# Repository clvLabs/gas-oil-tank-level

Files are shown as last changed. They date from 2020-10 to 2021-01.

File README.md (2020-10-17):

# gas-oil-tank-level

Easy gas oil tank level meter using an Arduino and a *ping* sensor

## Hardware

* Arduino Nano
* Ping sensor
* OLED screen
  * 2 3K3 resistors (I2C pullups)
* 2 buttons
  * 2 10K resistors (pullups)

## Software

### Requirements

This project has been developed with PlatformIO, you can compile it with the stock Arduino IDE, but you'll have a nicer time with PlatformIO...

### Configuration

Keeping both buttons pressed for `BUTTON_HOLD_TIME` will enter configuration mode, in which you can set `MIN_LEVEL_CM` and `MAX_LEVEL_CM`. These settings will be stored on EEPROM.

To change other settings you have to edit `src/config.h`.

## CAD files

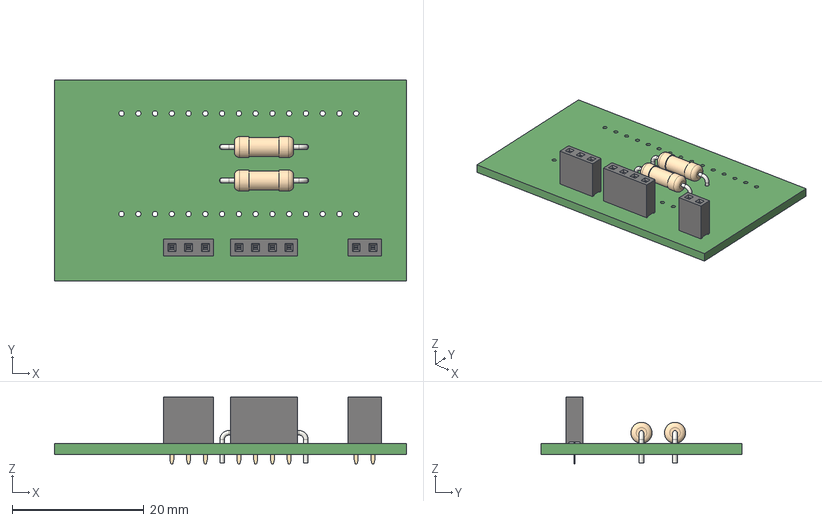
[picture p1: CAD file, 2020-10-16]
resources/schematics/main-board-multi/main-board/3d/main-board.step
53.3 x 30.5 x 10.1 mm

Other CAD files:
resources/schematics/main-board-multi/main-board/3d/main-board.stl

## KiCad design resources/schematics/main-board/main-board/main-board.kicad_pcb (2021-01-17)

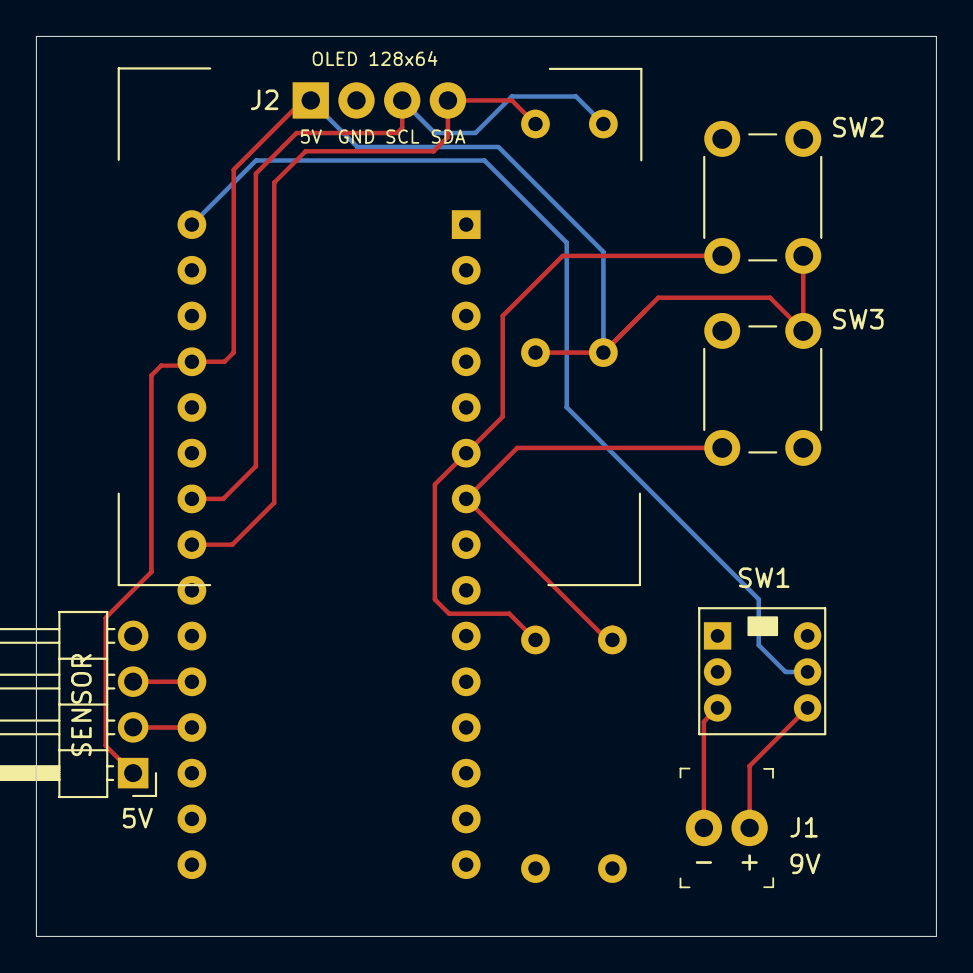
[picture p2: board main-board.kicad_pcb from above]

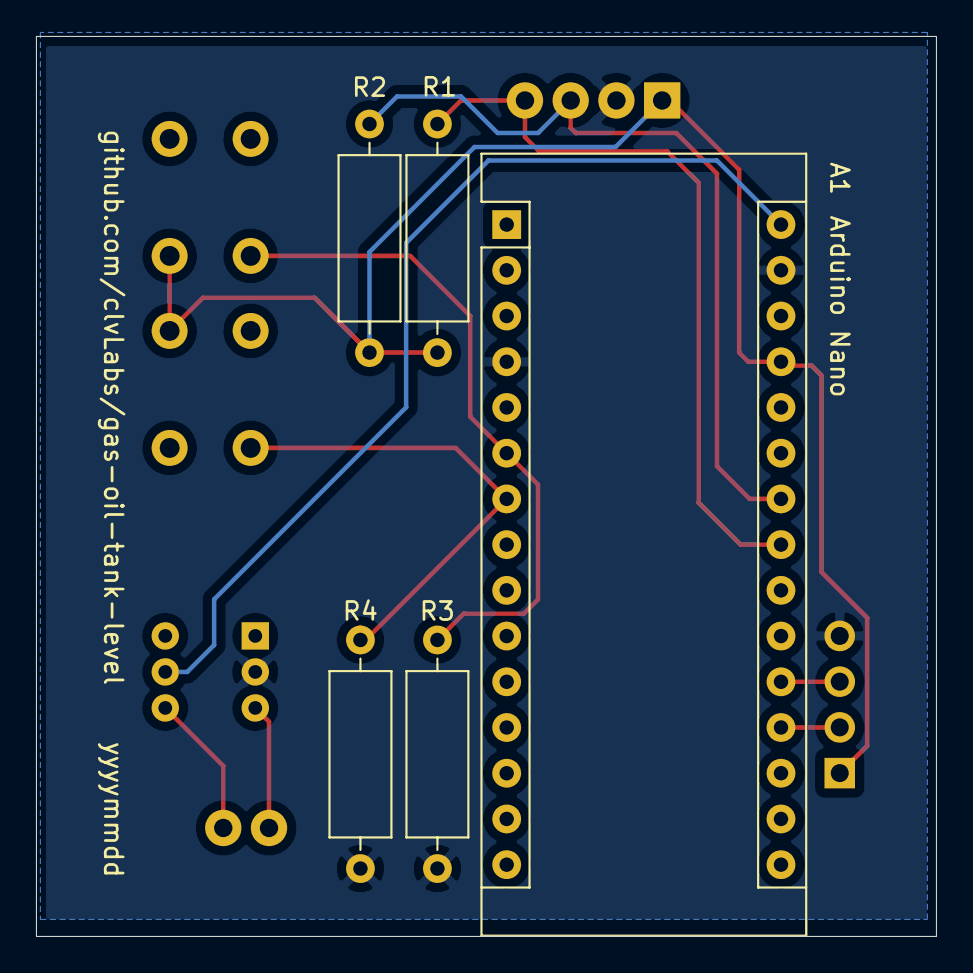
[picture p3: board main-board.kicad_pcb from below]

Board: 2 copper layers, 50.0 x 50.0 mm, 11 parts (5 on the bottom side), 11 nets.

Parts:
A1: Arduino_Nano_v3.x; Arduino_Nano
J1: Conn_01x02_Female; PinHeader_1x2_P2.54mm_Drill1.02mm
J2: Conn_01x04_Female; OLED_128X64
J3: Conn_01x04_Female; PinHeader_1x04_P2.54mm_Horizontal
R1, R2: 3.3K; R_Axial_DIN0309_L9.0mm_D3.2mm_P12.70mm_Horizontal
R3, R4: 10K; R_Axial_DIN0309_L9.0mm_D3.2mm_P12.70mm_Horizontal
SW1: SW_Push_DPDT; Switch_DPDT_7x7mm
SW2, SW3: SW_Push_45deg; SW_PUSH_6mm_H7.3mm

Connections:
+5V: A1.27, J2.1, J3.1, R1.1, R2.1, SW2.2, SW3.2
BATT_GND: J1.1, SW1.3
BATT_VIN: J1.2, SW1.6
BUTTON_DOWN_PIN: A1.7, R4.2, SW3.1
BUTTON_UP_PIN: A1.6, R3.2, SW2.1
GND: A1.4, A1.29, J2.2, J3.4, R3.1, R4.1, SW1.2
I2C_SCL: A1.24, J2.3, R2.2
I2C_SDA: A1.23, J2.4, R1.2
PING_ECHO_PIN: A1.20, J3.3
PING_TRIGGER_PIN: A1.19, J3.2
VIN: A1.30, SW1.5

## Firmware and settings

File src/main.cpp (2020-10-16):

#include "Arduino.h"
#include "3rdParty/JC_Button/JC_Button.h"
#include "config.h"
#include "utils/eepromcfg.h"
#include "ui/uimgr.h"

// Globals
DISPLAY_CLASS u8g(U8G_I2C_OPT_NONE | U8G_I2C_OPT_DEV_0); // I2C / TWI
Button btnUp(BUTTON_UP_PIN, BUTTON_DEBOUNCE_MS, BUTTON_INTERNAL_PULLUP, BUTTON_INVERT);
Button btnDown(BUTTON_DOWN_PIN, BUTTON_DEBOUNCE_MS, BUTTON_INTERNAL_PULLUP, BUTTON_INVERT);
ui::UIMgr uiMgr;
EEPROMCfg cfg;

void setup()
{
#ifdef SERIAL_OUTPUT_ENABLED
    Serial.begin(9600);
    Serial.println("Jelou!");
#endif

    pinMode(PING_TRIGGER_PIN, OUTPUT);
    pinMode(PING_ECHO_PIN, INPUT);

    pinMode(BUTTON_UP_PIN, INPUT);
    pinMode(BUTTON_DOWN_PIN, INPUT);

    u8g.setColorIndex(1);
    btnUp.begin();
    btnDown.begin();

    uiMgr.setup(&cfg, &u8g, &btnUp, &btnDown);
}

void loop()
{
    uiMgr.loop();
    delay(LOOP_SLEEP_MS);
}

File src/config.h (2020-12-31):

#pragma once

#include "Arduino.h"
#include "U8glib.h"

// Program EEPROM signature
static const int PROGRAM_EEPROM_SIGNATURE = 3014;

// Serial output (comment to disable)
// #define SERIAL_OUTPUT_ENABLED

// Distance sensor
static const uint8_t PING_TRIGGER_PIN = A0;
static const uint8_t PING_ECHO_PIN = A1;
static const unsigned int PING_MAX_DISTANCE = 500; // See NewPing.h

// Main loop sleep
static const int LOOP_SLEEP_MS = 10;

// Buttons
static const uint8_t BUTTON_DEBOUNCE_MS = 25;
static const bool BUTTON_INTERNAL_PULLUP = false;
static const bool BUTTON_INVERT = false;
static const int BUTTON_HOLD_TIME = 2000;
static const int BUTTON_RAMP1_TIME = 500;
static const int BUTTON_RAMP2_TIME = 4000;

static const uint8_t BUTTON_UP_PIN = 3;
static const uint8_t BUTTON_DOWN_PIN = 4;

// Display
#define DISPLAY_CLASS U8GLIB_SSD1306_128X64
static const int DISPLAY_WIDTH = 128;
static const int DISPLAY_HEIGHT = 64;
static const int DISPLAY_MINX = 0;
static const int DISPLAY_MINY = 0;
static const int DISPLAY_MAXX = DISPLAY_MINX + DISPLAY_WIDTH - 1;
static const int DISPLAY_MAXY = DISPLAY_MINY + DISPLAY_HEIGHT - 1;

// Level calibration
static const unsigned int MIN_LEVEL_CM_DEFAULT = 100;
static const unsigned int MAX_LEVEL_CM_DEFAULT = 19;

// Low battery alarm
static const long LOWBATT_PANIC_MODE_THRESHOLD_MV = 2000; // 2.000V

// Blink timing
static const unsigned int BLINK_ON_TIME = 500;
static const unsigned int BLINK_OFF_TIME = 500;

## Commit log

2019-12-21 Initial prototype
2019-12-28 Switch to Arduino Nano
2019-12-28 Show bar / voltage
2019-12-28 Blink battery voltage as alarm
2020-01-31 Add schematic/pcb
    [main-board-B_Cu.gbr, main-board-B_Mask.gbr, main-board-B_SilkS.gbr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]
2020-02-12 Calibrate BOTTOM_CM for my tank
2020-02-13 Calibrate TOP_CM for my tank
2020-10-15 Add ramp mode for buttons
2020-10-16 Add board 3D model
    [main-board.step, main-board.stl]
2020-12-31 Refactor PCB - batch-20201231
    [main-board-B_Cu.gbr, main-board-B_Mask.gbr, main-board-B_SilkS.gbr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]
2020-12-31 Update calibration for my tank
2021-01-10 Add horizontal pin header for connector
    [main-board.kicad_pcb, main-board.sch]
2021-01-17 Update footprints
    [main-board.kicad_pcb]
